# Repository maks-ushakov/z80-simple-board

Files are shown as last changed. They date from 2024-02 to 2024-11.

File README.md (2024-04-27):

<p align="center">
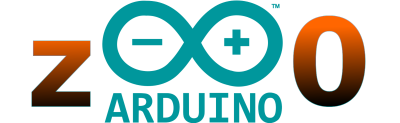
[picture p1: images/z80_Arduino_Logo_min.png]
z80 Arduino logo
    
</p>
<p align="center">
    <p align="center">Simple board based on Z80 CPU and 'modern' Arduino board</p>
    <p align="center"><a href="https://www.youtube.com/playlist?list=PLPrbpMWukRSoZ5geATjLQaH6BlcrjA2ah">Click here to have a look at the videos about variants</a></p>
</p>

# z80-simple-board

## About project

This project has a few purpouses:

- learn old assembly language for Intel 8080
- learn the features for z80
- replace ROM with bootloader based on Arduino
- use Arduino as app loader for RAM area
- use Arduino as simple serial IO for CPU

## Variants

Project is making step by step from simplest minimal to more complicated.

All files for each variant you can find in directory `variants`

|  directory | Memory| Brief |Ready|
|---|---|---|-----|
| test | 1B  | For testing CPU buses |  Y  |
|  minimal_16B | 16B | Minimum to see how CPU work with Memory and IO| Y |
|  minimal_32B | 32B | Minimum for learn assembly language | Y |
|  multiplex | 2KB | Minimal with commutator | N |
|  shift_32k |  32KB | Half memory system (shift registers) | N |
|  shift_64k |  64KB | Half memory system (shift registers) | N |

Variant difference

| Option | test | minimal_16B| minimal_32B| multiplex|  shift  |
|---|---|---|---|---|---|
| Memory | 0B | 16B | 32B, 64B | 1K, 2K | 32K,64K |
| Mem type | none | mocked| mocked | mocked | real |
|IO | none | mocked |  mocked | real | real|
|CPU Freq| 20Hz| 20Hz| 100Hz| 100Hz| 1Mhz |
|add. chips| - | - | - | cd4017 | 74htc595, 8286, 8282|

## Structure

Each variant has own directories:

- `arduino` - for arduino scketches (with preloaded Z80 binary)
- `Assm` - assembly files and binares
- `doc` - some useful instructions

Also each project has Kicad schematics and Readme with requirements for that variant.

# How to use
## Arduino sketch

Clone this repository
```
git clone https://github.com/maks-ushakov/z80-simple-board.git
```

Choose variant you want to use.

Load Arduino sketch

Use Variant readme to change preloaded memory.
Change Memory array with z80 C-style-array code you want to be loaded to z80 memory

Load sketch to arduino

## How to make z80 binary from assebler source

You can use any file extensions for sourse and binary files.  Common extensions for sourses are `.s`, '.asm', 'z80', for binary are `.bin` or none, `lst` for listing files.
I use `.z80` for assembly source and `bin` for binary.

__If you have z80asm__

```
z80asm --output=<file_name>.bin <file_name>.z80
```

__If you use VASM__
```
vasmz80_oldstyle -Fbin -o <file_name>.bin -Lall -L <file_name>.lst <file_name>.z80
```

```
vasmz80_std -Fbin -o <file_name>.bin -Lall -L <file_name>.lst <file_name>.z80
```

__Online__

By asm80 or ORG IDE

## Binary to readable table

```
xxd -g 1 <file_name>.bin
```

## Binary to arduino array

```
xxd -i <file_name>.bin
```

## Serial terminals
Minicom
```
minicom -b 9600 -D /dev/ttyUSB0
```

Screen
```
screen /dev/ttyUSB0 9600
```

If you do not have access to ttyUSB0  (Arduino or terminal app still connect to /dev/ttyUSB0)

```
fuser -k /dev/ttyUSB0
```

## Load binary manually by console

use command `P` or `M` to load values started by address
```
> P <addr> <data> <data> <data> ...
```
```
> m <addr> <data> <data> <data> ...
```

to check memory use command `D`

```
> D <start_addr> <end_addr>
```

## Load binary with XMODEM protocol

// TODO

## Steps
Test. First run.

   Arduino Nano as Clock generator and Buffer.

   Resources: `variants/test`

Arduino as Memory and IO port.
   Minimal System. 16B memory. Any IO port is Arduino
   Arduino as universal chipset.

   Resources:`variants/minimal_16B`

Arduino as Memory loader and simple OS
    Minimal System, 32B memory. Arduino has command line interface to load code

    Resources: `variants/minimal_32_64B`

## TODO

- More memory 32B or 64B. Arduino Console

- LCD as IO port. Bus Buffering (in progress)

- Mocked memory with multiplexer/commutator (in progress)

- 32k RAM chip. DMA. CPU give acces to bus (featured)

- Block load XMODEM (featured)

- Monitor (BIOS) via Arduino Serial (featured)

- PPA 8255. Address detector. (featured)

 -Timer 8253 and Interrupt controller (featured)

## Useful Sources

__Links__:

[z80 User Manual](http://www.zilog.com/docs/z80/um0080.pdf)

[Arduino Language References](https://docs.arduino.cc/programming/)

[Arduino Pinout](https://docs.arduino.cc/resources/pinouts/A000005-full-pinout.pdf)

[z80 info](http://www.z80.info/) - a lot of information about z80, his perioferial chips instruction sets and tutorials

[VASM](http://www.compilers.de/vasm.html) - portable assembler for different CPUs

[ORG IDE](https://clrhome.org/asm/) - online z80 IDE

[asm80](https://www.asm80.com/) - online IDE and emulator

__Other z80 projects__ when I get some ideas, shematic principles and code examples:

[Grant Searl z80 system](http://searle.x10host.com/) some boards has CP/M and BASIC, they used serial terminal

[Wichit Sirichote z80 kit](https://kswichit.net/Z80/Z80.html) has z80 binary for Monitor(BIOS)

[Wichit Sirichote i8085 kit](https://kswichit.net/mtk-85/index.html) has Assembly source code for Monitor(BIOS)

[CPU ville](http://cpuville.com/Kits/Z80-kits-home.html)

__Books__ (some books you can find on [z80 info Books](http://www.z80.info/z80books.htm)):

Build your own Z80 computer. Design guidelines and application notes. Ciarcia, S. 1981

Programming the Z80. Zaks Rodnay, 1981

From homemade devices on logic elements to microcomputers. USSR. Bartenev V., Alginin B. 1993 (About i8080)

Simplest micro-ECM. USSR. Bureev L.N. 1989 (About i8080 with simplest  BIOS)

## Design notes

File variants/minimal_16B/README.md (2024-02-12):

# Z80-Arduino minimal_16B

Connect Arduino Nano to Z80 CPU and use it as 16B memory and IO device.

## About

Useful for watchindg how to CPU deal with instructions, data and IO ports.

## Technical details

Memory 16 Byte reapeted on full address area. Memory placed in Arduino array.
Any IO device is Arduino

Memory array: variable code in sketch

## Components

- z80 CPU
- Arduino Nano
- Power supply module
- breadboard

## Start

- Power ON

- Check LEDs outputs

- Press reset a few seconds

- See Outputs on Serial Monitor or Serial Terminal

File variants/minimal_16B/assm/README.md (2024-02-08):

# Examples for 16 bait System

## Files
.zasm - assembler program
.z80 - raw binary

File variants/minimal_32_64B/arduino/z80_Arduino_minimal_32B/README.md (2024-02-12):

# Z80-Arduino test

Connect Arduino Nano to Z80 CPU and use it as 16B memory.

## Pin connections

|  Z80 |  Arduino pins  |  pin mode |
|---|---|---|
|  M1  | D2 | IN |
|  MREQ| A0 | IN |
|  IORQ| D12 | IN |
|  RD  | A1 | IN |
|  WR  | A2 | IN |
|  A0  | D3 | IN |
|  A1  | A3 | IN |
|  A2  | A4 | IN |
|  A3  | A5 | IN |
|  D0  | D8 | OUT |
|  D1  | D9 | OUT |
|  D2  | D10 | OUT |
|  D3  | D11 | OUT |
|  D4  | D4 | OUT |
|  D5  | D5 | OUT |
|  D6  | D6 | OUT |
|  D7  | D7 | OUT |
| CLK  | D13 | OUT |

## Start

- Power ON

- Press reset a few seconds

- See Outputs on Serial monitor

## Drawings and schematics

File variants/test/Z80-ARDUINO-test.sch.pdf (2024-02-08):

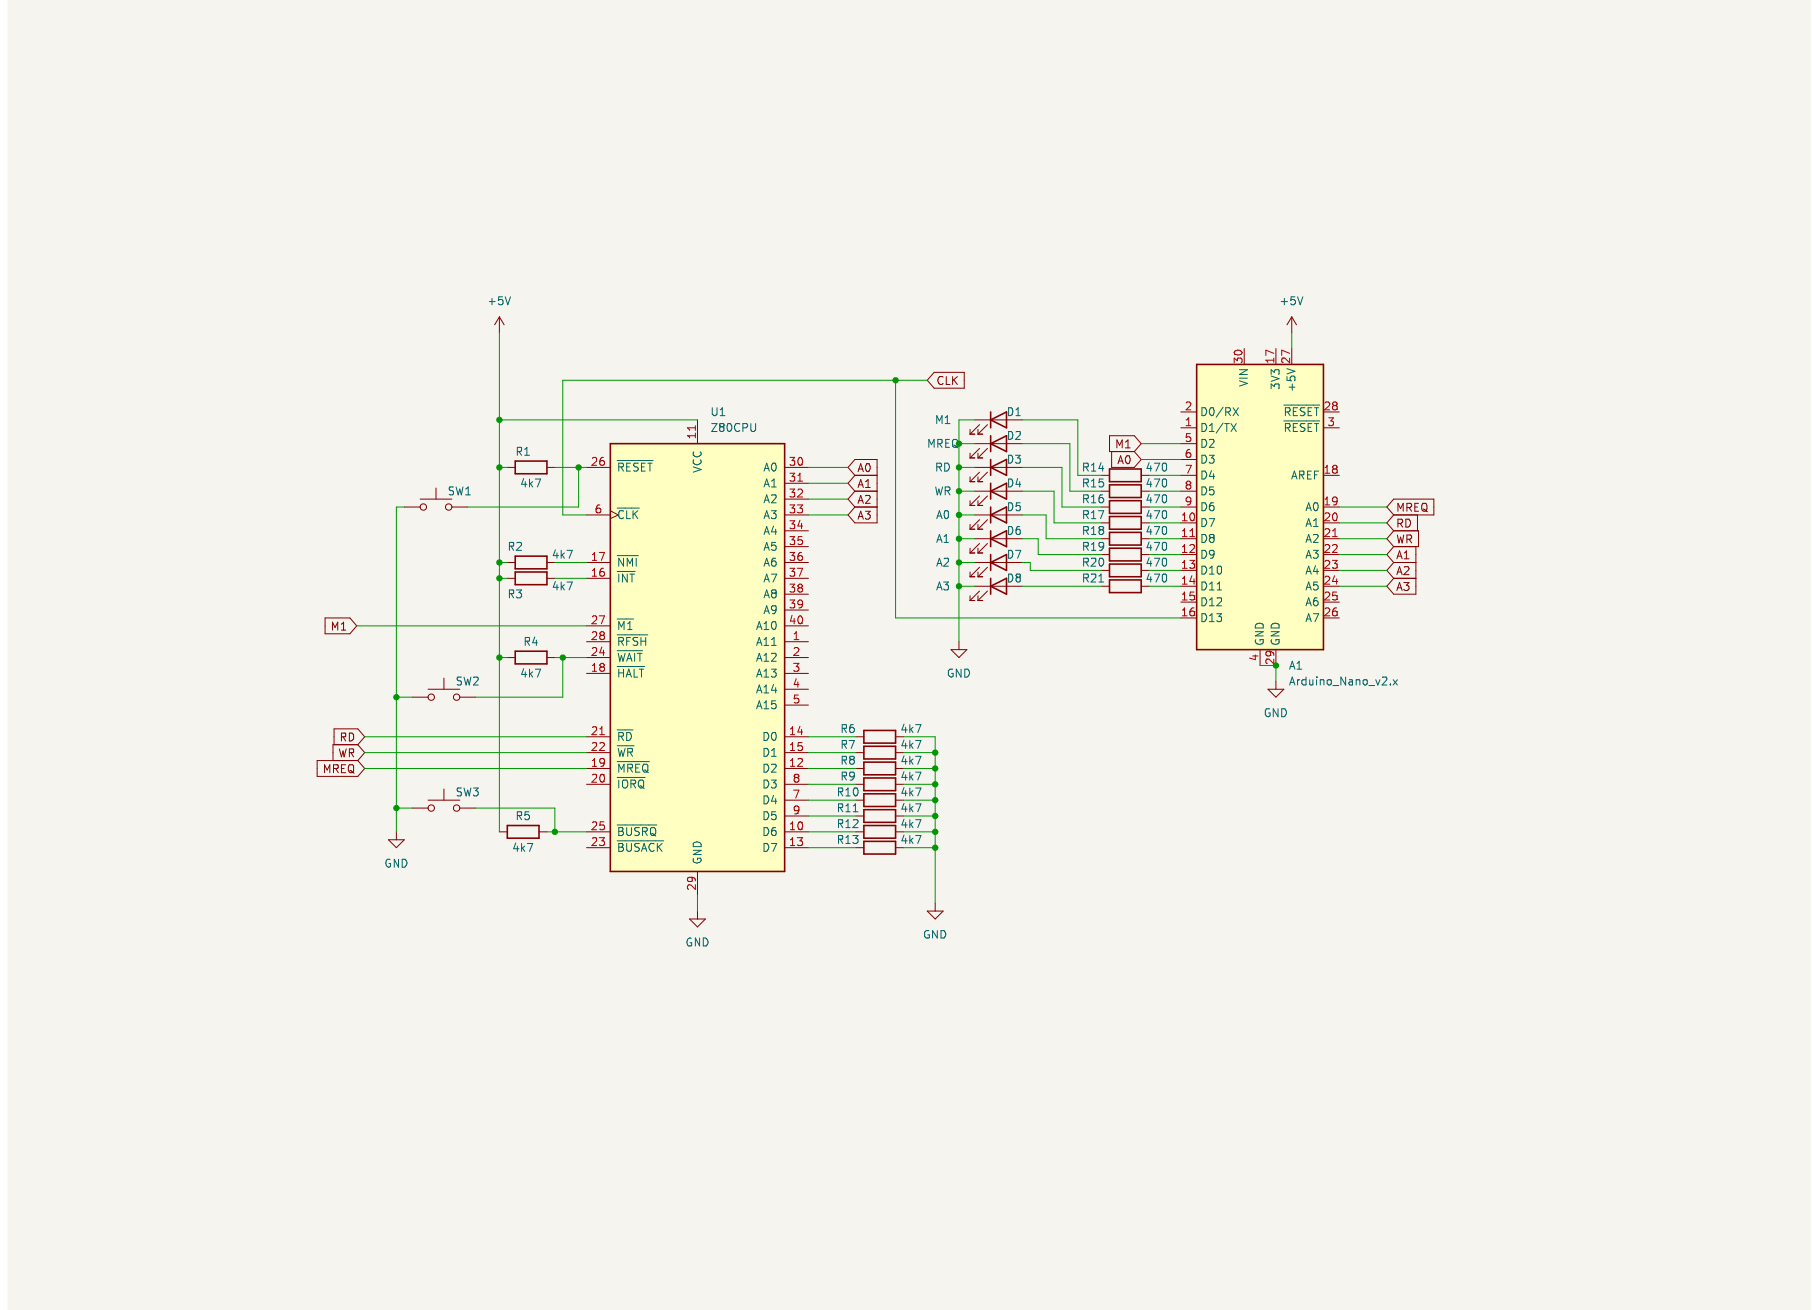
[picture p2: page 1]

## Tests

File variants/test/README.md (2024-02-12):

# Z80-Arduino test

Connect Arduino Nano to Z80 CPU and use it as buffer for LEDs.

## About

Simplest 1 Byte 1 Command System. Useful for watchindg timing diagrams and how to CPU switch address and system bus

## Components

- z80 CPU
- Arduino Nano
- Power supply module
- breadboard

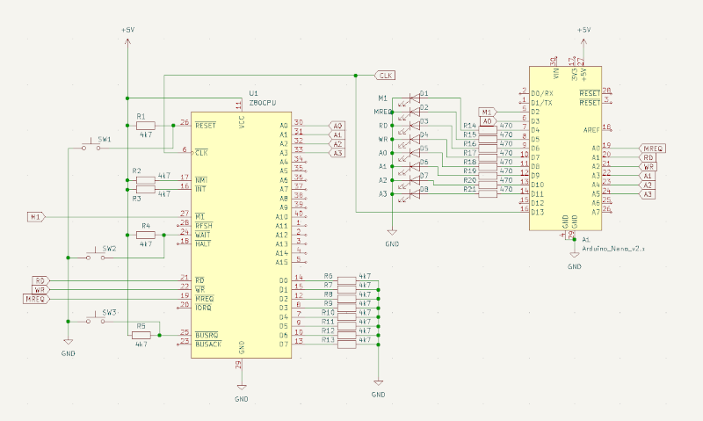
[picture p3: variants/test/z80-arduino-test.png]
Z80 Arduino Schema


## Start

- Power ON

- Check LEDs outputs

- Press reset a few seconds

- See Outputs on LEDs

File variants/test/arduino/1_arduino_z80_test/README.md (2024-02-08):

# Z80-Arduino test

Connect Arduino Nano to Z80 CPU and use it as buffer for LEDs.

## Pin connections

|  Z80 |  Arduino Inputs|  Arduino Outputs|
|---|---|---|
|  M1  | 2 | 4 |
|  MREQ| A0 | 5 |
|  RD  | A1 | 6 |
|  WR  | A2 | 7 |
|  A0  | 3 | 8 |
|  A1  | A3 | 9 |
|  A2  | A4 | 10 |
|  A3  | A5 | 11 |

Z80 Arduino Schema

## Start

- Power ON

- Check LEDs outputs

- Press reset a few seconds

- See Outputs on LEDs

## Timing diagram
You can connect the logical probe to CPU pins

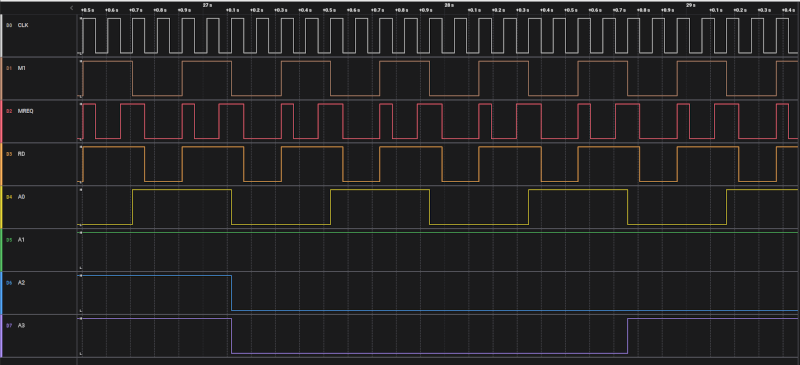
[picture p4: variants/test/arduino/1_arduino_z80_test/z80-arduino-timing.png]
Z80 Arduino Timing


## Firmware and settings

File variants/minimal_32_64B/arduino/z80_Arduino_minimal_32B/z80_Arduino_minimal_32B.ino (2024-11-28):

/**
 * Z80+Arduino. Main controller
 * Use for handle data on board memory
 * Autoboot (load data) after reset.
 * Read memory cells, read block, write values by hand or from files
 */
#include "Config.h"
#include "CPU_Board.h"
#include "CPUMemoryLoader.h"
#include "z80A_commands.h"

uint8_t DEBUG = 0;

bool showPrompt = true;
String prompt = "> ";

enum {
  CTRL_RUN,
  CTRL_BUSRQ,
  CTRL_BUS_USED,
};

#if defined(CPU_IO_MOCKED)
  #include "MockIO.h"
  uint8_t out_status = 0;
  uint8_t in_status = 0;
  MockIO mockio;
#endif

#if defined(CPU_MEMORY_MOCKED)
uint8_t read_status = 0;
uint8_t write_status = 0;
#endif

CPUBoard cpu;
MemoryLoader memory(MEMORY_SIZE);
Commands mon;
String commandBuffer = " ";

void debug_print(String, String, uint16_t, uint8_t, uint8_t);

void setup() {
  cpu.init();
  cpu.setClock(4); // 4 -> about 100Hz
  memory.init(&cpu);
  mon.init(&memory);
  #if defined(CPU_IO_MOCKED)
    mockio.init();
    mon.setIO(&mockio);
  #endif
  #if defined(MEM_AUTOLOAD_ON)
    for (uint16_t i = 0; i < NUM_CHUNKS; i++) {
      memory.loadChunk(memoryChunks[i]);
    }
  #endif
  Serial.begin(9600);
  Serial.print(F("CPU Board "));
  Serial.print(CPU_NAME);
  Serial.print("+Arduino v");
  Serial.println(CPU_BOARD_VERSION);
  // Serial.flush();
}

void loop()
{
  unsigned long currentMillis = millis();
  cpu.tick(currentMillis);

  if (showPrompt) {
    // Serial.println();
    Serial.print(prompt);
    showPrompt = false;
  }

  uint8_t cmd_status = readCommandLine(&commandBuffer, 80);
  if (cmd_status == CMD_ST_READY) {
    Serial.flush();
    mon.setCommandLine(&commandBuffer);
    int8_t command = mon.parseCommand();
    if (command != CMD_NONE) {
      Serial.println();
      mon.execute(command);
      showPrompt = true;
    }
    commandBuffer = " ";
    cmd_status = CMD_ST_WAIT;
  }
  
  #if defined(CPU_MEMORY_MOCKED) or defined(CPU_IO_MOCKED)
    // Read control lines
    uint8_t rd, wr;
    uint8_t addr = cpu.getAddr();
    rd = digitalRead(IN_RD);
    wr = digitalRead(IN_WR);
    #if defined(CPU_MEMORY_MOCKED)
      uint8_t mreq = digitalRead(IN_MREQ);
      // CPU Fetch Data. Active signas are LOW
      if(read_status == 0 && mreq == LOW && rd == LOW) {
      uint8_t data = memory.getByte(addr);
        cpu.setData(data);
        read_status = 1;
        debug_print("MREQ", "RD", addr, data);
      } else if (read_status == 1 && (mreq == HIGH || rd == HIGH)) {
        read_status = 0;
        cpu.setAsDataInput();
      }

      if(write_status == 0 && mreq == LOW && wr == LOW) {
      uint8_t data = cpu.getData();
      memory.setByte(addr, data);
        write_status = 1;
        debug_print("MREQ", "WR", addr, data);
      } else if (write_status == 1 && (mreq == HIGH || wr == HIGH)) {
        write_status = 0;
        cpu.setAsDataInput();
      }
    #endif
      
    #if defined(CPU_IO_MOCKED)
      uint8_t iorq = digitalRead(IN_IORQ);
      // CPU send data to Port. Active signas are LOW
        if(out_status==0 && iorq == LOW && rd == LOW) {
        uint8_t data = mockio.getInputData();
        cpu.setData(data);
        out_status = 1;
        debug_print("IORQ", "RD", addr, data);
      } else if (out_status==1 && (iorq == HIGH || rd == HIGH)) {
        out_status = 0;
      }
      
      if(in_status==0 && iorq == LOW && wr == LOW) {
        in_status = 1;
        uint8_t data = cpu.getData();
        mockio.setOutPort(addr, data);
        debug_print("IORQ", "WR", addr, data);
      } else if (in_status==1 && (iorq == HIGH || wr == HIGH)) {
        in_status = 0;
      }
    #endif
  #endif
}

/**
 * Print debug information
 * 
 * String area - Show Is it Memory (MREQ) or IO port (IORQ)
 * String operation - RD - read, WR - write
 * uint16_t addr - Physical 16bit address
 * uint8_t data - 8bit data
 * uint_8t m1 - State of M1
 */  
void debug_print(String area, String operation, uint16_t addr, uint8_t data) {
    if(DEBUG) {
	    Serial.flush();
	    Serial.print(area);
      Serial.print('\t');
      Serial.print(operation);
      Serial.print('\t');
      Serial.print(addr,  HEX);
      Serial.print('\t');
      Serial.println(data);
	}
}

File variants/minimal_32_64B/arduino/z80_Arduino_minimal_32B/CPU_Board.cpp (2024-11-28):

#include "Arduino.h"
#include "CPU_Board.h"
#include "Config.h"

CPUBoard::CPUBoard() {
  control_pins[0] = IN_MREQ;
  control_pins[1] = IN_RD;
  control_pins[2] = IN_WR;
  control_pins[3] = IN_IORQ;

  addr_pins[0] = IN_A0;
  addr_pins[1] = IN_A1;
  addr_pins[2] = IN_A2;
  addr_pins[3] = IN_A3;
  addr_pins[4] = IN_A4;
  addr_pins[5] = IN_A5;
};

void CPUBoard::init() {
  // put your setup code here, to run once:
  // Set Clock output
  pinMode(CLK_PIN, OUTPUT);

    // Set Address lines as input
  for (uint8_t i; i < MEMORY_LINES; i++) {
  	pinMode(addr_pins[i], INPUT);
  }
  // set Control lines as input
  for (uint8_t i; i < 4; i++) {
  	pinMode(control_pins[i], INPUT);
  }
  
  setAsDataInput();
}

void CPUBoard::tick(unsigned long currentMillis) {
    if(currentMillis - previousMillis > _interval) {
    // if the CLK_PIN is off turn it on and vice-versa:
    if (_clk_State == LOW)
      _clk_State = HIGH;
    else
      _clk_State = LOW;
    // set the CLK_PIN with the clk_CPU_State of the variable:
    digitalWrite(CLK_PIN, _clk_State);
    // save the last time you toggle the CLK_PIN 
    previousMillis = currentMillis; 
  }
};

void CPUBoard::setClock(long period) {
  _interval = period;
}

void CPUBoard::setAsDataInput() {
  // set  as input
  DDRD = DDRD & 0x0f;
  DDRB = DDRB & 0xf0;
  // no pull_up
  PORTD = PORTD & 0x0f;
  PORTB = PORTB & 0xf0;
}

/**
 * Take address from addr pins
 */ 
uint8_t CPUBoard::getAddr() {
	uint8_t addr = 0;
  for(uint8_t i = 0; i < MEMORY_LINES; i++) {
    addr += digitalRead(addr_pins[i])<<i;
  }
  return addr;
}

/**
 * Give data to port
 */ 
void CPUBoard::setData(uint8_t data) {
  DDRD = DDRD | 0xF0;
  DDRB = DDRB | 0x0F;
  uint8_t portdClone, portbClone;
  portdClone = PORTD & 0x0F | (data & 0xF0);
  portbClone = PORTB & 0xF0 | (data & 0xF);
  PORTD = portdClone;
  PORTB = portbClone;
}

/**
 * Take data from port
 */ 
uint8_t CPUBoard::getData() {
  setAsDataInput();
  // get value
  uint8_t data = 0;
  data += PINB & 0xf;
  data += PIND & 0xf0;
  
  return data;
}

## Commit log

2024-02-08 Test2. Arduino as Memory and IO port
    [z80-test2-ram-rom-port.kicad_sch]
2024-02-12 Change structure
    [z80-test2-ram-rom-port.kicad_sch]
2024-02-14 Add assembly examples for LCD
    [z80-board-lcd-port.kicad_sch]
2024-02-15 Fix arduino sketch structure
    [CPU_Board.cpp, z80A_commands.cpp, z80_Arduino_minimal_32B.ino]
2024-02-15 Make aproximate schematic
    [step_debug.kicad_sch, z80-Arduino_minmal_32B.kicad_sch]
2024-04-18 Update version
    [z80-Arduino_minmal_32B.kicad_sch]
2024-04-27 Fix 32
    [z80-Arduino_minmal_32B.kicad_sch]
2024-04-27 Before video changes
    [z80-board-lcd-port.kicad_sch]
2024-11-28 Fix changes before IDDLE
    [z80-Arduino_minmal_32B.kicad_sch]
2024-11-28 Add last changes
    [z80-Arduino_minmal_32B_extend.kicad_sch, z80-board-simple_out_port.kicad_sch]
